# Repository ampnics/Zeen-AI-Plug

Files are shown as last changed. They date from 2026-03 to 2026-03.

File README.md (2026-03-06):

# Zeen-AI-Plug (Zero Green AI Plug)

Top-img

> An open-source, single-channel AI-powered smart plug built on ESP32-S3 with online (Sinric Pro / Google Home / Alexa) and offline timer-based control-designed and shared for the engineering community.

Mode-img

Bottom-img

---

## 📺 Full Course-Hardware Design With AI Co-Pilot

This project is part of a complete open-source hardware design course on YouTube:

**▶️ [Hardware Design With AI Co-Pilot-Full Playlist](https://youtube.com/playlist?list=PLxgq6Jtu7shR8w3cHLHZtZtIrhJVOUqG1&si=Gfo0e48VRceQaZlR)**

The course covers the complete design journey-from schematic to PCB layout, firmware, and cloud integration.

---

---

## 📋 Table of Contents

- [Overview](#-overview)
- [Features](#-features)
- [Hardware Specifications](#-hardware-specifications)
- [System Architecture](#-system-architecture)
- [Operating Modes](#-operating-modes)
- [Repository Structure](#-repository-structure)
- [Getting Started](#-getting-started)
- [Firmware Setup](#-firmware-setup)
- [Cloud & Voice Assistant Integration](#-cloud--voice-assistant-integration)
- [Manufacturing](#-manufacturing)
- [Contributing](#-contributing)
- [License](#-license)

---

## 🔍 Overview

The **Zeen-AI-Plug (ZAP-01A)** is an open-source, single-channel smart plug designed for the engineering community. It combines an ESP32-S3 microcontroller with cloud-based AI voice assistants and a robust offline timer mode, making it functional even without an internet connection.

The board runs on **220VAC mains input**, converting it to **5V DC** via an onboard HLK-5M05 power supply module, and further to **3.3V** via an AMS1117-3.3 LDO - powering the ESP32-S3 and all peripherals.

---

## ✨ Features

- ✅ Single-channel relay control (SPDT)
- ✅ Online mode - Sinric Pro, Google Home, Amazon Alexa
- ✅ Offline mode - RTC-based (DS3231M) timer control
- ✅ USB-C (USB 2.0) for firmware flashing
- ✅ ESD protection on USB lines (USBLC6-2P6)
- ✅ Onboard RTC with battery backup (DS3231M + CH291-1220LF)
- ✅ Status LEDs - Network, Error, General indication
- ✅ Buzzer feedback (MLT-8530)
- ✅ 4x tactile switches for local control
- ✅ MOV surge protection (10D561K)
- ✅ Screw terminal output for load connection
- ✅ Fiducial markers for PCB assembly
- ✅ Fully open-source - Hardware + Firmware

---

## 🔧 Hardware Specifications

| Parameter | Details |
|---|---|
| Microcontroller | ESP32-S3-WROOM-1 |
| Input Voltage | 220V AC |
| Operating Voltage | 5V DC / 3.3V DC |
| Power Supply Module | HLK-5M05 (220VAC → 5VDC) |
| LDO Regulator | AMS1117-3.3 |
| Relay | SPDT — 1 Channel |
| RTC | DS3231M (I2C) |
| RTC Battery | CH291-1220LF (Coin Cell) |
| USB Connector | USB-C (USB 2.0) |
| ESD Protection | USBLC6-2P6 |
| Surge Protection | MOV 10D561K |
| Fuse | 500mA / 250V |
| Status LEDs | Red, Blue, Green |
| Buzzer | MLT-8530 |
| Switches | 4x Tactile + 1x Boot + 1x Reset |
| PCB Tool | KiCad 9.0.1 |
| Board Revision | Rev-v0.1.0A |

---

## 🏗️ System Architecture

```
220V AC Input
     │
     ▼
[F1 Fuse 500mA] ──→ [MOV RV1 Surge Protection]
     │
     ▼
[HLK-5M05] ──→ 5V DC
     │
     ├──→ [Relay K1 SPDT] ──→ Load Output (Screw Terminal J2)
     │
     └──→ [AMS1117-3.3] ──→ 3.3V DC
               │
               ├──→ [ESP32-S3-WROOM-1] ←→ WiFi / BLE
               ├──→ [DS3231M RTC] (I2C)
               ├──→ [Status LEDs]
               ├──→ [Buzzer MLT-8530]
               ├──→ [Tactile Switches x4]
               └──→ [USB-C] ──→ Firmware Flash / Serial Debug
```

---

## ⚙️ Operating Modes

### 🌐 Online Mode
- Connects to WiFi and syncs with **Sinric Pro** cloud platform
- Voice control via **Google Home** and **Amazon Alexa**
- Remote control from anywhere via smartphone app
- Real-time status sync across all platforms

### 📴 Offline Mode
- Fully functional without internet connection
- **DS3231M RTC** maintains accurate time even after power loss
- Timer-based scheduling stored locally
- Local switch control always active in both modes

---

## 📁 Repository Structure

```
Zeen-AI-Plug/
├── Docs/
│   ├── 1-Datasheet/           # Component datasheets
│   ├── 2-Images/              # PCB photos, product images
│   ├── 3-Pin-Mapping/         # ESP32-S3 pin mapping reference
│   └── 4-Testing-Note/        # Test procedures and results
├── Firmware/
│   ├── 1-Test-Code/           # Individual peripheral test sketches
│   └── 2-ZAP-01A-Firmware/    # Main production firmware
├── Hardware/
│   ├── 1-External-3D-Models/  # 3D models for KiCad
│   ├── 2-External-Libraries/  # Custom KiCad footprints & symbols
│   ├── 3-Manufacturing-Files/ # Gerbers, BOM, CPL
│   └── 4-ZAP-01A/             # KiCad project files
└── README.md
```

---

## 🚀 Getting Started

### Prerequisites
- [KiCad 9.0.1](https://www.kicad.org/) — for hardware files
- [Arduino IDE](https://www.arduino.cc/en/software) or [VS Code + ESP-IDF](https://docs.espressif.com/projects/esp-idf/en/latest/) — for firmware
- [Sinric Pro Account](https://sinric.pro/) — for cloud integration
- ESP32-S3 board support package installed in Arduino IDE

### Clone the Repository
```bash
git clone https://github.com/ampnics/Zeen-AI-Plug.git
cd Zeen-AI-Plug
```

---

## 💻 Firmware Setup

### 1. Install ESP32-S3 Board Support
In Arduino IDE → Preferences → add this URL:
```
https://raw.githubusercontent.com/espressif/arduino-esp32/gh-pages/package_esp32_index.json
```
Then: **Tools → Board → Boards Manager → search "esp32" → Install**

### 2. Install Required Libraries
```
Sinric Pro
ArduinoJson
WebSockets
NTPClient
RTClib (for DS3231)
```

### 3. Configure Credentials
Open `Firmware/2-ZAP-01A-Firmware/` and update:
```cpp
For WiFi press "SET" button for 10Sec for updating WiFi Credential via AP Mode
#define APP_KEY         "your_sinric_app_key"
#define APP_SECRET      "your_sinric_app_secret"
#define SWITCH_ID       "your_sinric_device_id"
```

### 4. Flash the Firmware
- Connect via **USB-C**
- Select Board: `ESP32S3 Dev Module`
- Press & hold **BOOT (SW1)** → tap **RESET (SW2)** → release BOOT
- Click **Upload**

---

## ☁️ Cloud & Voice Assistant Integration

### Sinric Pro Setup
1. Create account at [sinric.pro](https://sinric.pro)
2. Add new device → **Smart Plug**
3. Copy **App Key**, **App Secret**, **Device ID** into firmware
4. Flash firmware — device appears online automatically

### Google Home
1. Open Google Home app → **"+" → Set up device**
2. Search **"Sinric Pro"** → Link account
3. Your ZAP-01A plug appears as a controllable device
4. Say: *"Hey Google, turn on the plug"*

### Amazon Alexa
1. Open Alexa app → **Skills & Games**
2. Search **"Sinric Pro"** → Enable skill → Link account
3. Discover devices
4. Say: *"Alexa, turn on the plug"*

---

## 🏭 Manufacturing

Fabrication files are located in `Hardware/3-Manufacturing-Files/` and include:

- **Gerber files** - for PCB fabrication
- **BOM (Bill of Materials)** - component list with values and part numbers
- **CPL (Component Placement List)** - for SMT assembly

> ⚠️ **Safety Warning:** This board operates at **220V AC mains voltage**. Always ensure proper insulation and safety precautions during assembly and testing. Do not touch the board while connected to mains power.

---

## 🤝 Contributing

Contributions are welcome from the engineering community!

1. Fork the repository
2. Create your feature branch: `git checkout -b feature/your-feature`
3. Commit your changes: `git commit -m "feat: add your feature"`
4. Push to the branch: `git push origin feature/your-feature`
5. Open a **Pull Request**

**Commit message convention:**

| Prefix | Use for |
|---|---|
| `hw:` | Hardware / KiCad changes |
| `fw:` | Firmware changes |
| `docs:` | Documentation updates |
| `mfg:` | Manufacturing file updates |
| `fix:` | Bug fixes |

---

## 📄 License

This project is licensed under the **MIT License** — see the [LICENSE](LICENSE) file for details.

You are free to use, modify, and distribute this project for personal and commercial purposes with attribution.

---

## Designed By

**Md Ammar Maniyar** - [LinkedIn](https://www.linkedin.com/in/ammarece/)

## Sponsered By
**NextPCB** - [NextPCB](https://www.nextpcb.com/?code=Ampnics)

## Explore More
**Ampnics** - [Ampnics](https://www.ampnics.com)

*Engineered in India 🇮🇳*

---

## Support the Project

If this project helped you, consider:

- **Starring** this repository
- **Subscribing** to the [YouTube Channel](https://www.youtube.com/@ampnics)
- **Forking** and contributing back to the project

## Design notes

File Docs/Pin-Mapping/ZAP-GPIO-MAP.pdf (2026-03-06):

Zeen-AI-Plug | GPIO Mapping
Device | GPIO | PIN | Type | Comment
3.3V | -- | 2 | PWR
GND | -- | 1/40 | PWR
VBUS | -- | -- | PWR
USB_D+ | IO20 | 14 | PROGRAM/DEBUG
USB_D- | IO19 | 13 | PROGRAM/DEBUG
SW1 | EN | 3 | IN
SW2 | IO0 | 27 | IN
SW3 | IO11 | 19 | IN
SW4 | IO12 | 20 | IN
SW5 | IO13 | 21 | IN
SW6 | IO14 | 22 | IN
RTC_sda | IO8 | 12 | COMM
RTC_scl | IO9 | 17 | COMM
DIS_sda | IO8 | 12 | COMM/OP
DIS_scl | IO9 | 17 | COMM/OP
OPT_dis_sda | IO17 | 10 | COMM/OP
OPT_dis_scl | IO18 | 11 | CPMM/OP
Relay | IO2 | 38 | OP
Network-LED | IO4 | 4 | OP
Status-LED | IO3 | 15 | OP
Buzzer | IO1 | 39 | OP

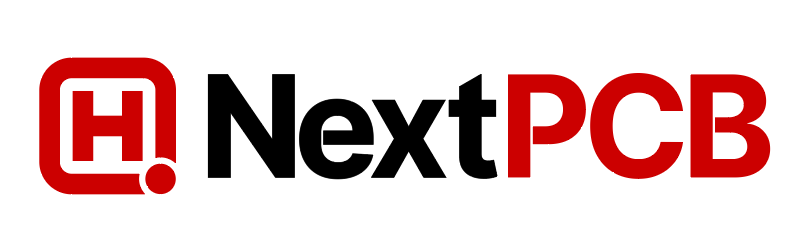
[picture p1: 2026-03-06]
Docs/Images/1746603675-2518-QAgOoc.png

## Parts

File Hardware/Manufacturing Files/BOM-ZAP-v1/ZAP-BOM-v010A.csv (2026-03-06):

S/N | Designator* | Quantity* | Manufacturer Part Number* | Package/Footprint | Description
1 | BT1 | 1 | XDCR-1220-006 | CH291-1220LF:BAT_CH291-1220LF | CH291-1220LF
2 | C1,C12,C13,C16 | 4 | CL21A106KAYNNNE | Capacitor_SMD:C_0805_2012Metric | 10uF
3 | C2,C3,C4,C5,C6,C7,C15,C17 | 8 | TCC0603X7R104K101CT | Capacitor_SMD:C_0603_1608Metric | 100nF
4 | C8,C11,C14 | 3 | TCC0603X7R104K101CT | Capacitor_SMD:C_0603_1608Metric | 100nF/50V
5 | C9 | 1 | MP2104K27C3X6LC | Capacitor_THT:C_Rect_L13.0mm_W6.0mm_P10.00mm_FKS3_FKP3_MKS4 | 0.1uF
6 | C10 | 1 | RVT220UF25V67RV0093 | Capacitor_SMD:CP_Elec_8x10 | 220uF
7 | D1 | 1 | XL-302SURD | LED_THT:LED_D3.0mm | RED
8 | D2 | 1 | B5819W | Diode_SMD:D_SOD-123 | B5819W
9 | D3,D4 | 2 | 1N4148W | Diode_SMD:D_SOD-123 | 1N4148W
10 | D5 | 1 | XL-302UGD | LED_THT:LED_D3.0mm | GREEN
11 | D6 | 1 | XL-302UBD | LED_THT:LED_D3.0mm | BLUE
12 | D7 | 1 | D-060306B1/SS2/B1 | LED_SMD:LED_0603_1608Metric | RED
13 | F1 | 1 | 2009T500mA250V | Fuse:Fuse_Littelfuse_395Series | 500mA 250V
14 | J1 | 1 | HS96L03W2C03 | 0.96 128x64 SSD1315 I2C LCD, OLED, Graphic ROHS | Display
15 | J2 | 1 | DB128V-5.08-4P-GN-S | TerminalBlock:TerminalBlock_bornier-4_P5.08mm | Screw_Terminal_01x04
16 | J3 | 1 | KH-TYPE-C-16P | Connector_USB:USB_C_Receptacle_HCTL_HC-TYPE-C-16P-01A | USB_C_Receptacle_USB2.0_16P
17 | K1 | 1 | SRD-05VDC-SL-C | Relay_THT:Relay_SPDT_Hongfa_HF3F-L-xx-1ZL1T | Relay_SPDT
18 | LS1 | 1 | MLT-8530 | ul_MLT-8530:MLT-8530_JHE | MLT-8530
19 | PS1 | 1 | HLK-5M05 | Converter_ACDC:Converter_ACDC_Hi-Link_HLK-5Mxx | HLK-5M05
20 | Q1,Q2 | 2 | AO3400A | Package_TO_SOT_SMD:SOT-23 | AO3400A
21 | R1,R2,R3,R4 | 4 | RC0603JR-070RL | Resistor_SMD:R_0603_1608Metric | 0R
22 | R5,R14,R15,R16,R17 | 5 | RC0603FR-0710KL | Resistor_SMD:R_0603_1608Metric | 10K
23 | R6,R7,R9,R10,R11 | 5 | RC0603FR-074K7L | Resistor_SMD:R_0603_1608Metric | 4K7
24 | R8 | 1 | MF1/4W-1M±1%-OT52 | Resistor_THT:R_Axial_DIN0204_L3.6mm_D1.6mm_P7.62mm_Horizontal | 1M
25 | R12,R13 | 2 | RC0603FR-075K1L | Resistor_SMD:R_0603_1608Metric | 5K1
26 | R18,R19 | 2 | RC0603JR-070RL | Resistor_SMD:R_0603_1608Metric | 0E
27 | R20 | 1 | RC0603FR-07470RL | Resistor_SMD:R_0603_1608Metric | 470R
28 | R21,R22,R23,R24,R25,R26 | 6 | RC0603FR-071KL | Resistor_SMD:R_0603_1608Metric | 1K
29 | RV1 | 1 | 10D561K | Varistor:RV_Disc_D12mm_W5.8mm_P7.5mm | 10D561K
30 | SW1,SW3,SW4,SW5,SW6 | 5 | TC-1102-C-I-B | Button_Switch_THT:SW_PUSH_6mm | SW_Push
31 | SW2 | 1 | SKRKAHE020 | Button_Switch_SMD:SW_Push_SPST_NO_Alps_SKRK | SW_Push
32 | U1 | 1 | ESP32-S3-WROOM-1-N8 | RF_Module:ESP32-S3-WROOM-1 | ESP32-S3-WROOM-1
33 | U2 | 1 | DS3231SN# | Package_SO:SOIC-16W_7.5x10.3mm_P1.27mm | DS3231M
34 | U3 | 1 | AMS1117-3.3 | Package_TO_SOT_SMD:SOT-223-3_TabPin2 | AMS1117-3.3
35 | U4 | 1 | USBLC6-2P6 | Package_TO_SOT_SMD:SOT-666 | USBLC6-2P6

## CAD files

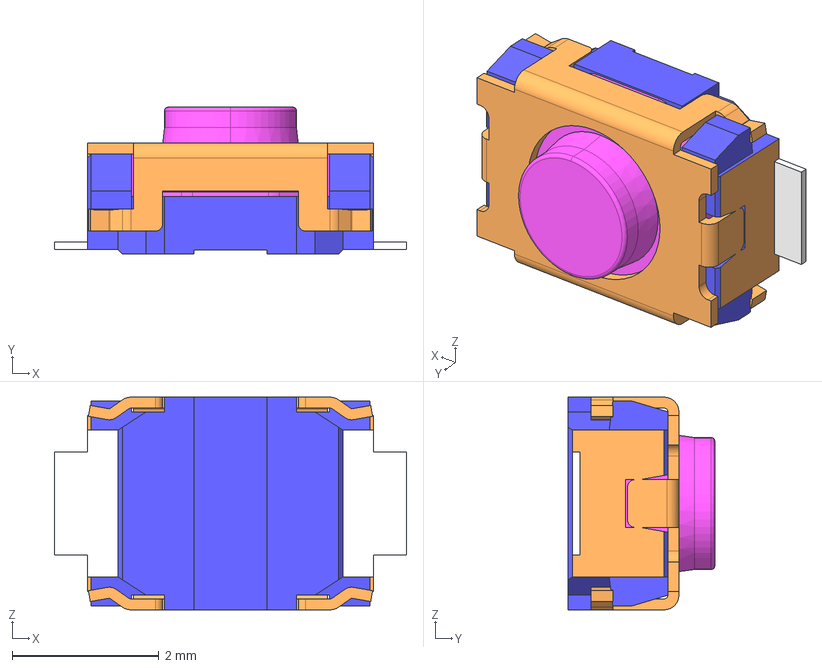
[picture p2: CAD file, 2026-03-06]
Hardware/External-3D-Models/skrkaee010.stp
4.80 x 2.00 x 2.90 mm

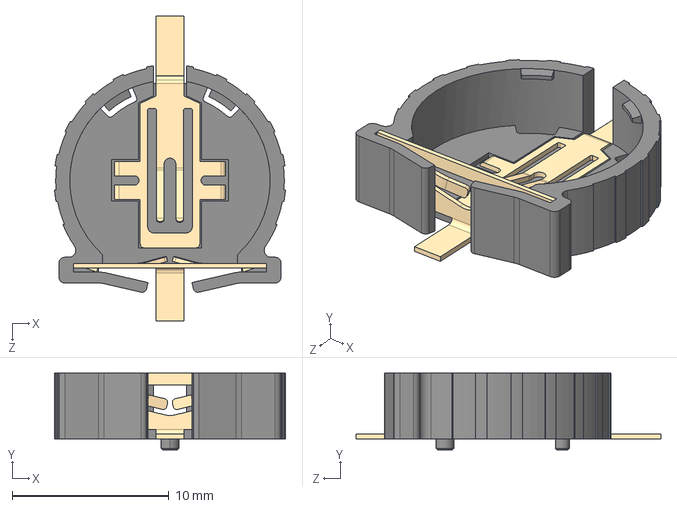
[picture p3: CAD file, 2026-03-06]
Hardware/External-libraries/CH291-1220LF/CH291-1220LF.step
14.7 x 4.90 x 19.4 mm

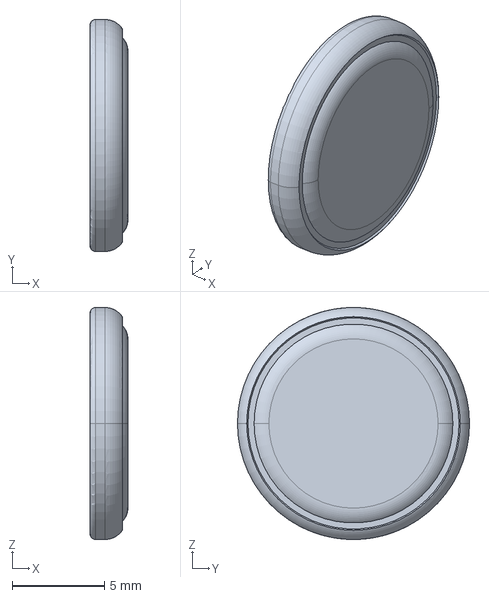
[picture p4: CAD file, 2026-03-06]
Hardware/External-3D-Models/k_cr1220_lithium-cell.stp
2.05 x 12.6 x 12.5 mm

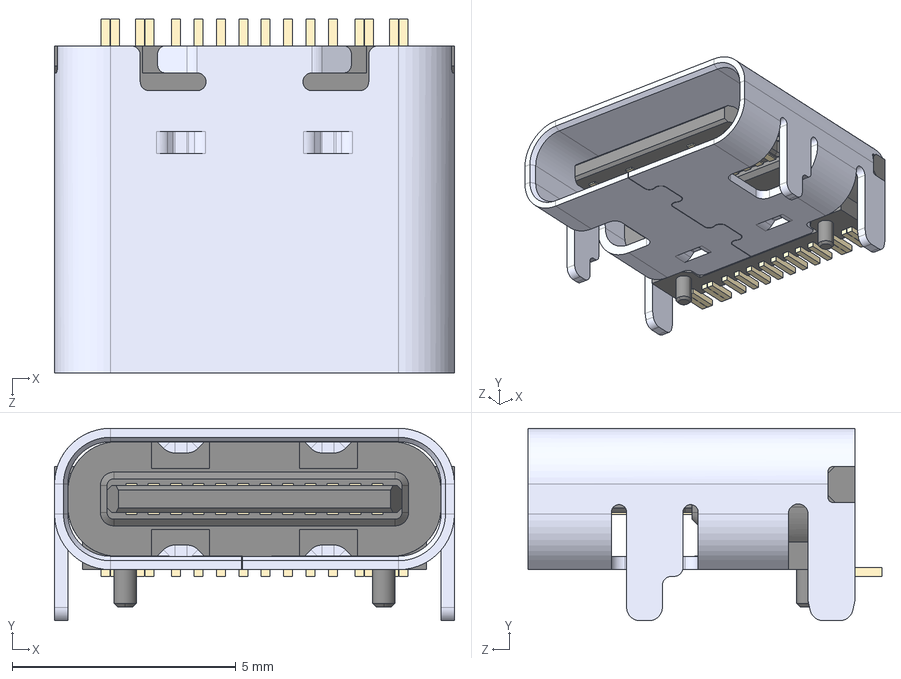
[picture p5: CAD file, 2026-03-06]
Hardware/External-3D-Models/TYPE-C-31-M-12--3DModel-STEP-56544.STEP
8.94 x 4.30 x 7.90 mm

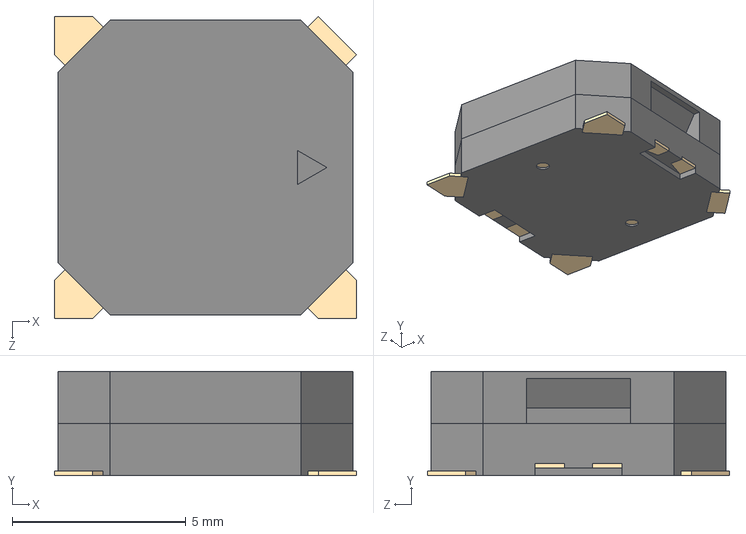
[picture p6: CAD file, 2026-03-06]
Hardware/External-3D-Models/MLT-8530--3DModel-STEP-269445.STEP
8.70 x 3.00 x 8.70 mm

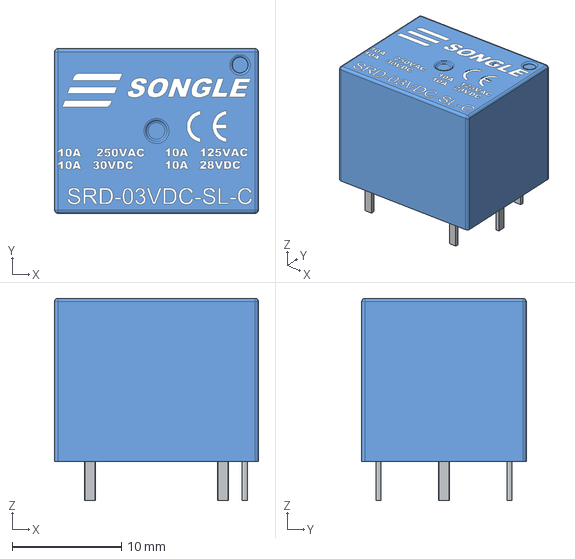
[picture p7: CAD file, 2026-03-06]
Hardware/External-3D-Models/Relay - SRD-03VDC-SL-C.stp
18.7 x 15.1 x 18.6 mm

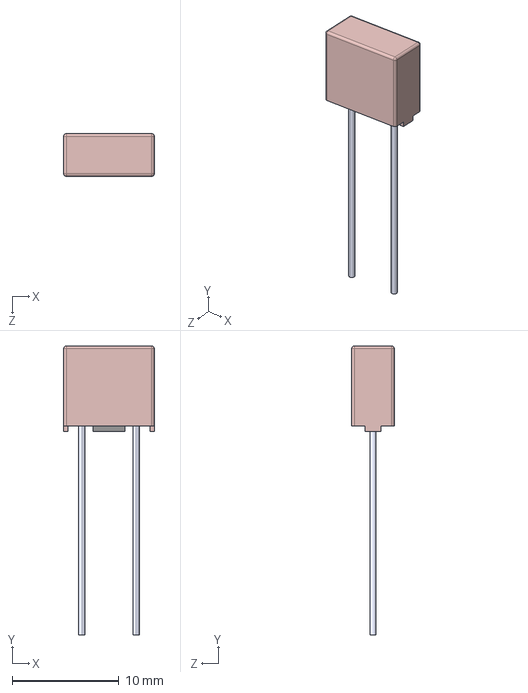
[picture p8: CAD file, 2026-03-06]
Hardware/External-3D-Models/39208000000.STEP
8.50 x 27.1 x 4.00 mm

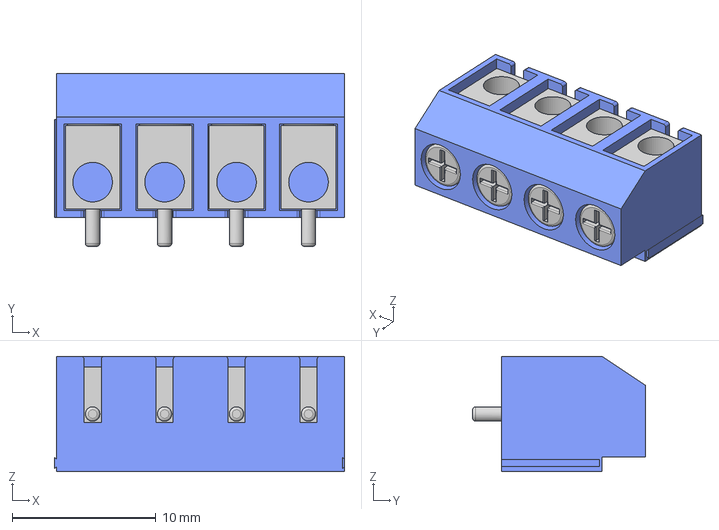
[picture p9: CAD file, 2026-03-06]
Hardware/External-3D-Models/Screw Terminal Block 5mm Blue 4-way.step
20.1 x 12.0 x 8.00 mm

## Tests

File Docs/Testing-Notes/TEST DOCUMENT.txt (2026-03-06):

TEST DOCUMENT 

Zeen-AI-Plug, v0.1.0A|Nov 2025

Test Points
TP1: MCU RESET/EN 
TP2: MCU BOOT
TP3: 5VDC
TP4: GND
TP5: TXD0
TP6: RXD0
TP7: 3.3VDC

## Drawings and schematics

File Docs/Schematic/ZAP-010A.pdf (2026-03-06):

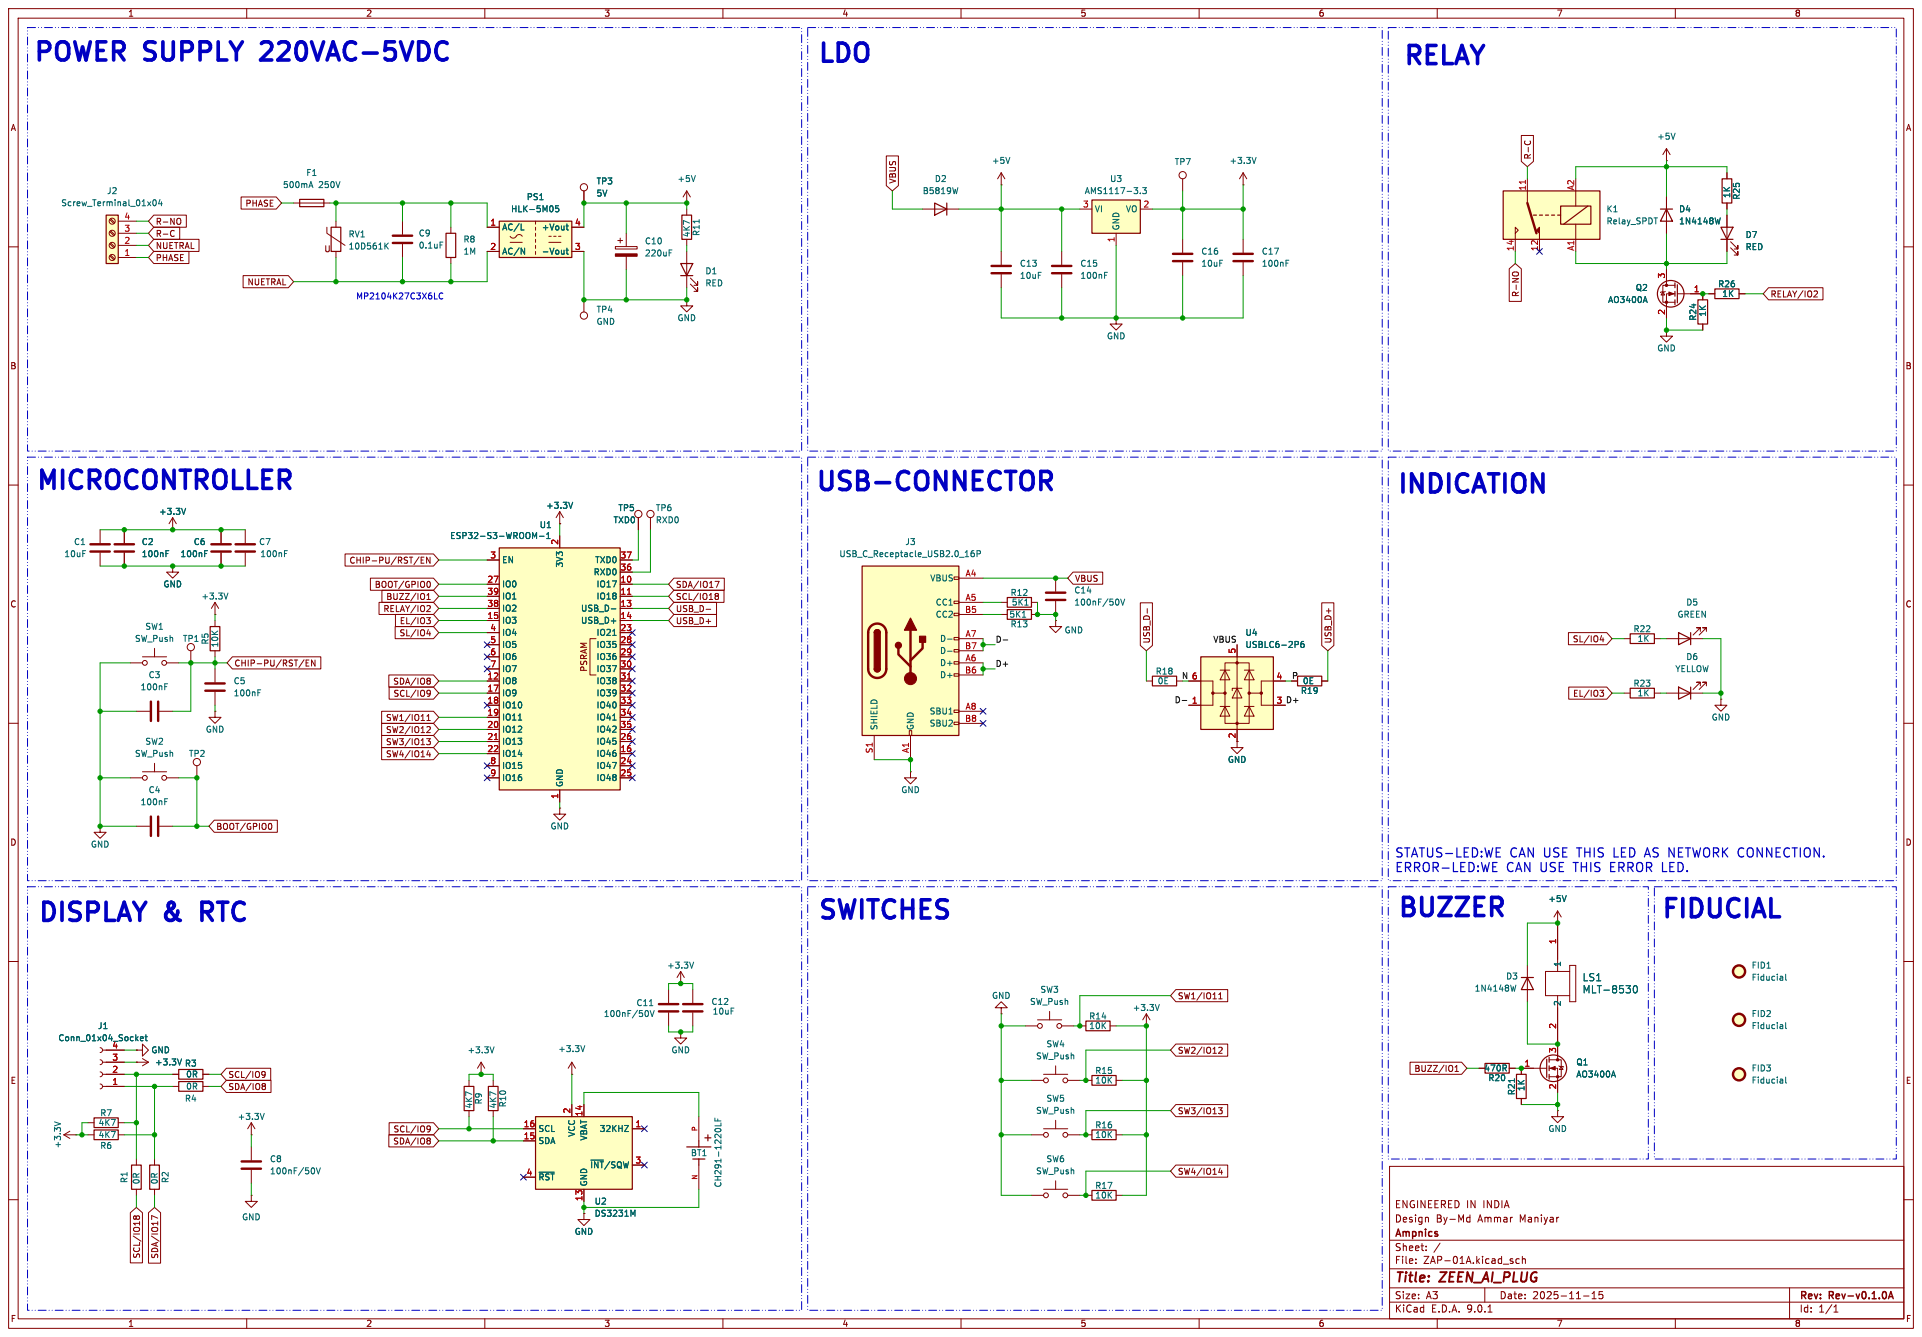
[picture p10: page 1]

P N BT1 CH291-1220LF SCL/IO18 USB_D+ SDA/IO17 NUETRAL R-NO

STATUS-LED:WE CAN USE THIS LED AS NETWORK CONNECTION.
ERROR-LED:WE CAN USE THIS ERROR LED.

File: ZAP-01A.kicad_sch Sheet: / Ampnics

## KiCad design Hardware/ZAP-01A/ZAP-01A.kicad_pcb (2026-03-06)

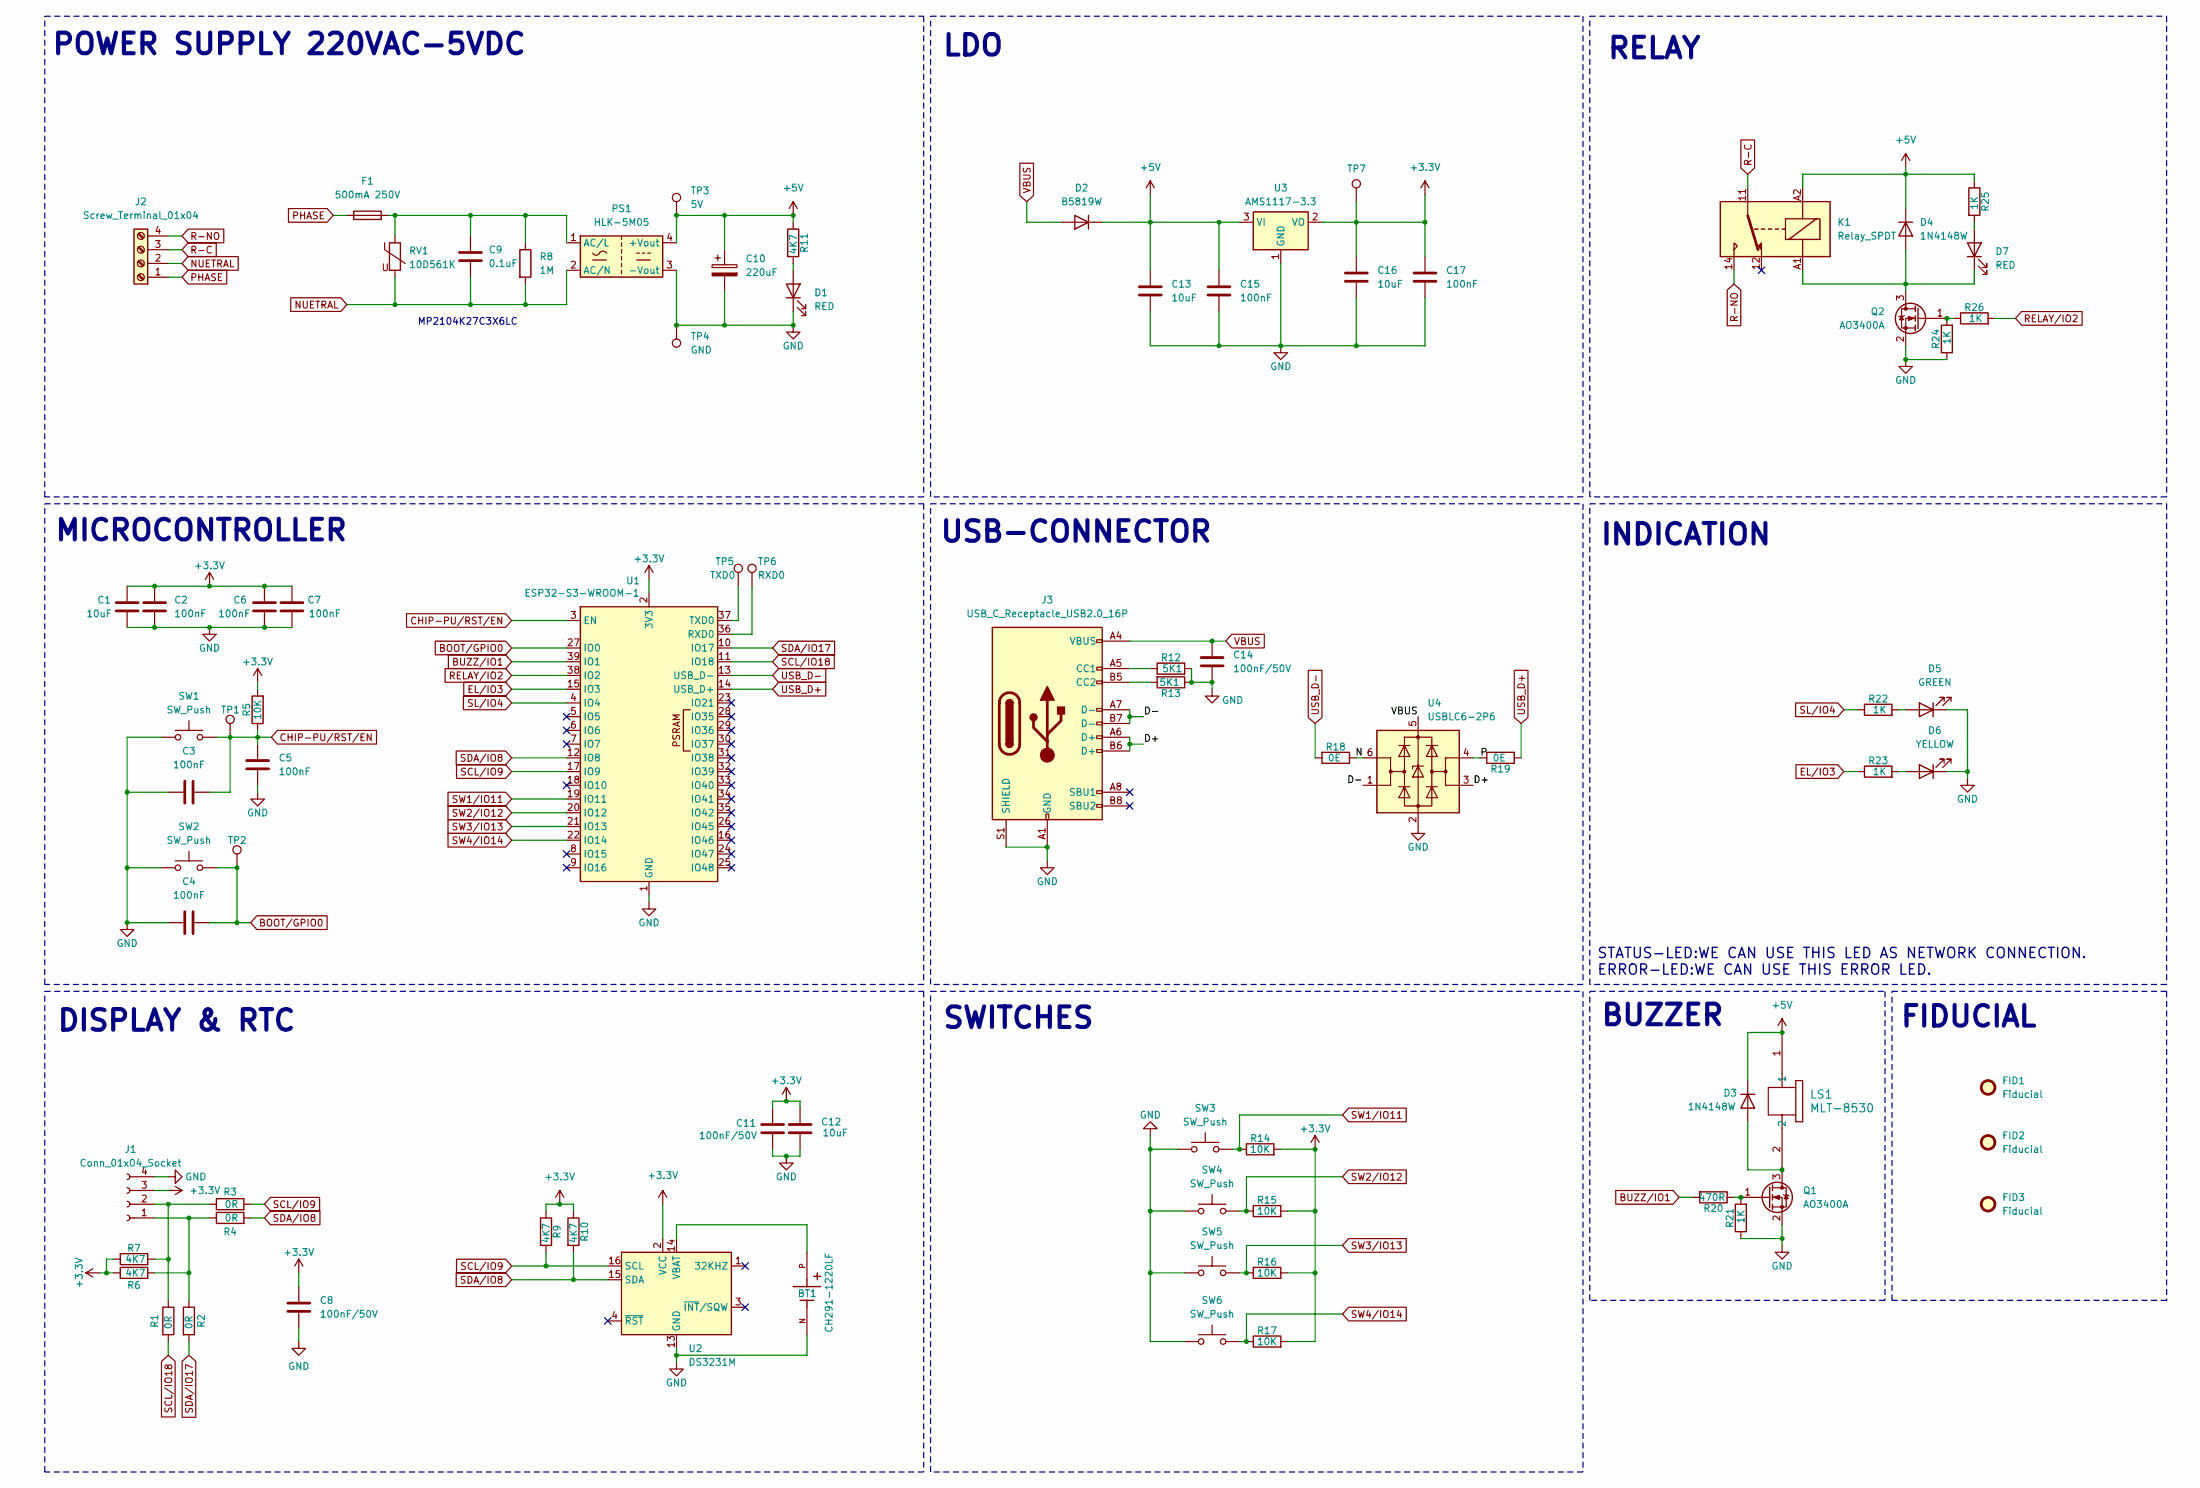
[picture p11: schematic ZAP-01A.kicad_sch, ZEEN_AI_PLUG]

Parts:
BT1: CH291-1220LF; BAT_CH291-1220LF; PARTREV A
C1, C12, C13, C16: 10uF; C_0805_2012Metric
C2, C3, C4, C5, C6, C7, C15, C17: 100nF; C_0603_1608Metric
C8, C11, C14: 100nF/50V; C_0603_1608Metric
C9: 0.1uF; C_Rect_L13.0mm_W6.0mm_P10.00mm_FKS3_FKP3_MKS4
C10: 220uF; CP_Elec_8x10
D1: RED; LED_D3.0mm
D2: B5819W; D_SOD-123
D3, D4: 1N4148W; D_SOD-123
D5: GREEN; LED_D3.0mm
D6: YELLOW; LED_D3.0mm
D7: RED; LED_0603_1608Metric
F1: 500mA 250V; Fuse_Littelfuse_395Series
FID1, FID2, FID3: Fiducial; Fiducial_0.75mm_Mask1.5mm
J1: Conn_01x04_Socket; PinSocket_1x04_P2.54mm_Vertical
J2: Screw_Terminal_01x04; TerminalBlock_bornier-4_P5.08mm
J3: USB_C_Receptacle_USB2.0_16P; USB_C_Receptacle_HCTL_HC-TYPE-C-16P-01A
K1: Relay_SPDT; Relay_SPDT_Hongfa_HF3F-L-xx-1ZL1T
LS1: MLT-8530; MLT-8530_JHE
PS1: HLK-5M05; Converter_ACDC_Hi-Link_HLK-5Mxx
Q1, Q2: AO3400A; SOT-23
R1, R2, R3, R4: 0R; R_0603_1608Metric
R5, R14, R15, R16, R17: 10K; R_0603_1608Metric
R6, R7, R9, R10, R11: 4K7; R_0603_1608Metric
R8: 1M; R_Axial_DIN0204_L3.6mm_D1.6mm_P7.62mm_Horizontal
R12, R13: 5K1; R_0603_1608Metric
R18, R19: 0E; R_0603_1608Metric
R20: 470R; R_0603_1608Metric
R21, R22, R23, R24, R25, R26: 1K; R_0603_1608Metric
RV1: 10D561K; RV_Disc_D12mm_W5.8mm_P7.5mm
SW1, SW3, SW4, SW5, SW6: SW_Push; SW_PUSH_6mm
SW2: SW_Push; SW_Push_SPST_NO_Alps_SKRK
TP1, TP2, TP7: 3.3V; TestPoint_Pad_D1.5mm
TP3: 5V; TestPoint_Pad_D1.5mm
TP4: GND; TestPoint_Pad_D1.5mm
TP5: TXD0; TestPoint_Pad_D1.5mm
TP6: RXD0; TestPoint_Pad_D1.5mm
U1: ESP32-S3-WROOM-1
U2: DS3231M; SOIC-16W_7.5x10.3mm_P1.27mm
U3: AMS1117-3.3; SOT-223-3_TabPin2
U4: USBLC6-2P6; SOT-666

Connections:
+3.3V: C1.1, C2.1, C6.1, C7.1, C8.1, C11.1, C12.1, C16.1, C17.1, J1.3, R5.2, R6.1, R7.1, R9.1, R10.1, R14.2, R15.2, R16.2, R17.2, TP7.1, U1.2 (3V3), U2.2 (VCC), U3.2 (VO)
+5V: C10.1, C13.1, C15.1, D2.1 (K), D3.1 (K), D4.1 (K), K1.A2, LS1.1, PS1.4 (+Vout), R11.1, R25.1, TP3.1, U3.3 (VI)
/D+: J3.A6 (D+), J3.B6 (D+), U4.3 (I/O2)
/D-: J3.A7 (D-), J3.B7 (D-), U4.1 (I/O1)
/N: R18.1, U4.6 (I/O1)
/P: R19.2, U4.4 (I/O2)
BOOT/GPIO0: C4.2, SW2.2, TP2.1, U1.27 (IO0)
BUZZ/IO1: R20.2, U1.39 (IO1)
CHIP-PU/RST/EN: C3.2, C5.1, R5.1, SW1.2, TP1.1, U1.3 (EN)
EL/IO3: R23.1, U1.15 (IO3)
GND: BT1.N, C1.2, C2.2, C3.1, C4.1, C5.2, C6.2, C7.2, C8.2, C10.2, C11.2, C12.2, C13.2, C14.2, C15.2, C16.2, C17.2, D1.1 (K), D5.1 (K), D6.1 (K), J1.4, J3.A1 (GND), J3.A12 (GND), J3.B1 (GND), J3.B12 (GND), J3.S1 (SHIELD), PS1.3 (-Vout), Q1.2 (S), Q2.2 (S), R12.2, R13.1, R21.1, R24.1, SW1.1, SW2.1, SW3.1, SW4.1, SW5.1, SW6.1, TP4.1, U1.1 (GND), U1.40 (GND), U1.41 (GND), U2.5 (GND), U2.6 (GND), U2.7 (GND), U2.8 (GND), U2.9 (GND), U2.10 (GND), U2.11 (GND), U2.12 (GND), U2.13 (GND), U3.1 (GND), U4.2 (GND)
unnamed: D1.2 (A), R11.2
unnamed: D3.2 (A), LS1.2, Q1.3 (D)
unnamed: D4.2 (A), D7.1 (K), K1.A1, Q2.3 (D)
unnamed: D5.2 (A), R22.2
unnamed: D6.2 (A), R23.2
unnamed: D7.2 (A), R25.2
unnamed: J1.1, R2.1, R4.1, R6.2
unnamed: J1.2, R1.1, R3.1, R7.2
unnamed: J3.A5 (CC1), R12.1
unnamed: J3.B5 (CC2), R13.2
unnamed: Q1.1 (G), R20.1, R21.2
unnamed: Q2.1 (G), R24.2, R26.1
unnamed: TP6.1, U1.36 (RXD0)
unnamed: TP5.1, U1.37 (TXD0)
unnamed: BT1.P, U2.14 (VBAT)
PHASE: F1.1, J2.1
R-C: J2.3, K1.11
R-NO: J2.4, K1.14
RELAY/IO2: R26.2, U1.38 (IO2)
SCL/IO9: R3.2, R9.2, U1.17 (IO9), U2.16 (SCL)
SCL/IO18: R1.2, U1.11 (IO18)
SDA/IO8: R4.2, R10.2, U1.12 (IO8), U2.15 (SDA)
SDA/IO17: R2.2, U1.10 (IO17)
SL/IO4: R22.1, U1.4 (IO4)
SW1/IO11: R14.1, SW3.2, U1.19 (IO11)
SW2/IO12: R15.1, SW4.2, U1.20 (IO12)
SW3/IO13: R16.1, SW5.2, U1.21 (IO13)
SW4/IO14: R17.1, SW6.2, U1.22 (IO14)
USB_D+: R19.1, U1.14 (USB_D+)
USB_D-: R18.2, U1.13 (USB_D-)
VBUS: C14.1, D2.2 (A), J3.A4 (VBUS), J3.A9 (VBUS), J3.B4 (VBUS), J3.B9 (VBUS), U4.5 (VBUS)

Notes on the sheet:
MICROCONTROLLER
BUZZER
DISPLAY & RTC
SWITCHES
INDICATION
MP2104K27C3X6LC
USB-CONNECTOR
RELAY
FIDUCIAL
LDO
POWER SUPPLY 220VAC-5VDC
STATUS-LED:WE CAN USE THIS LED AS NETWORK CONNECTION. ERROR-LED:WE CAN USE THIS ERROR LED.

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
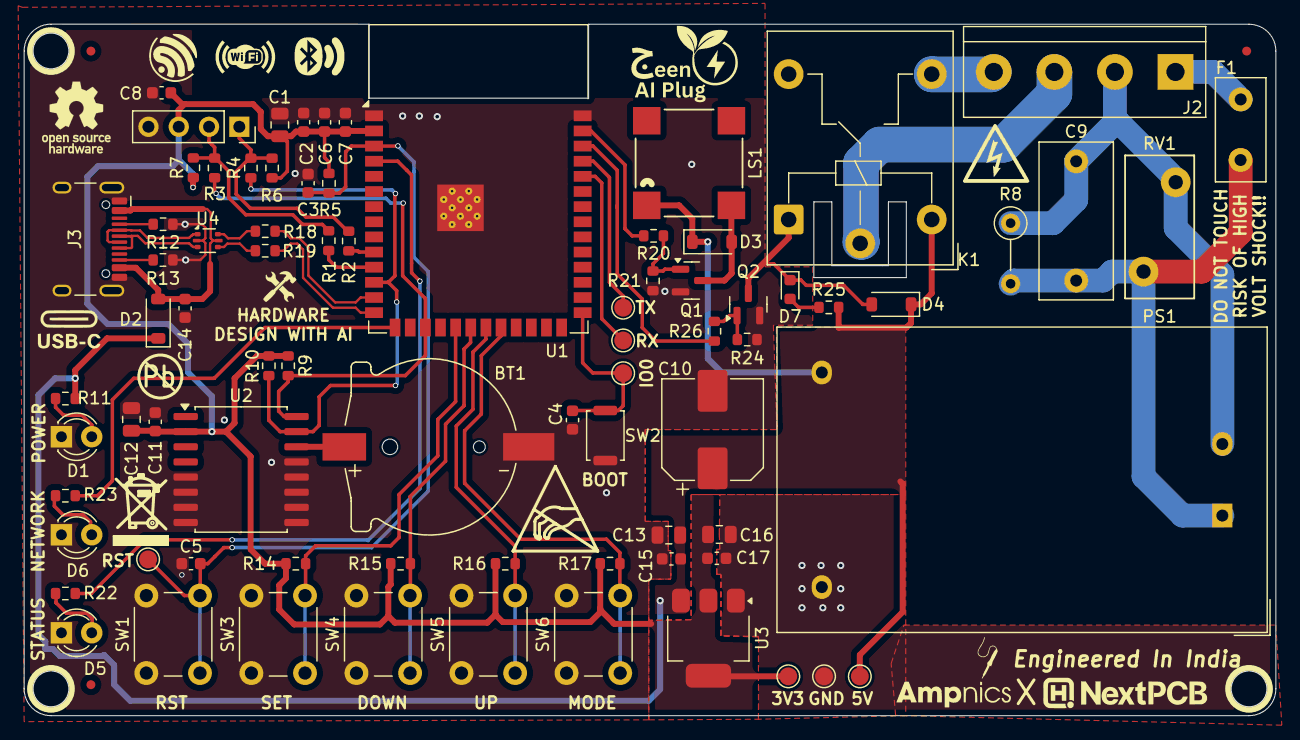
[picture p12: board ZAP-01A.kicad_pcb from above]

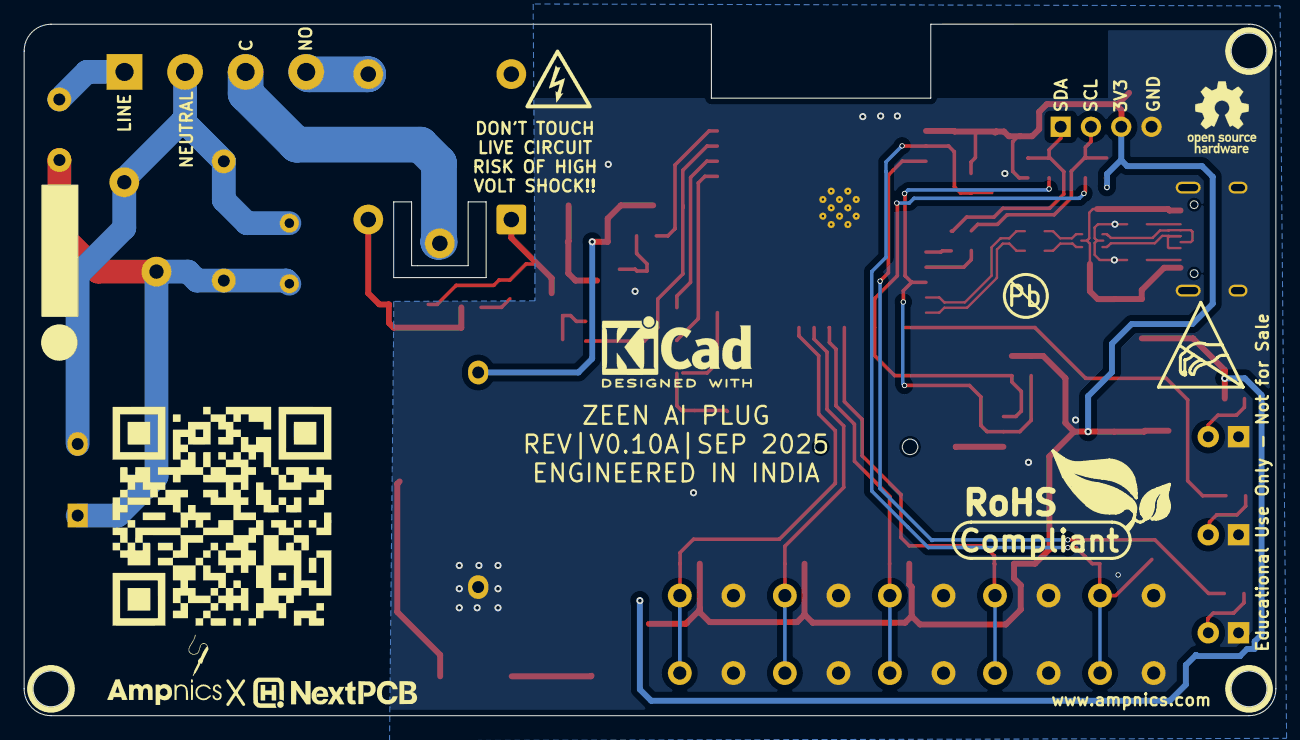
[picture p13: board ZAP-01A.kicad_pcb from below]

Board: 2 copper layers, 105.0 x 58.0 mm, 87 parts (3 on the bottom side), 44 nets.

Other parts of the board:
Sign-Antistatic: Val**; LOGO_ANTISTATIC_1
Sign-Antistatic#2: Val**; LOGO_ANTISTATIC_1
Sign-PbFree: LOGO_PBFREE
Sign-PbFree#2: LOGO_PBFREE
Sign-RecycleBin: LOGO_RECYCLEBIN_1
Sign-RoHS: Val**; LOGO_ROHS_1

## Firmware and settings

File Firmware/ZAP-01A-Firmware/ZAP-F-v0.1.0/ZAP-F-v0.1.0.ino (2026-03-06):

/* Zeen AI Plug - ESP32-S3 Timer Board (Online + Offline)
   Features:
   - Splash + C-scale on startup
   - Mode select: ONLINE / OFFLINE
   - ONLINE: WiFiManager + SinricPro control + OLED feedback
   - OFFLINE: Timer countdown with relay, buzzer & OLED
   - Perfect button debounce, single press & long press
   - Relay status LED
*/

#include <Arduino.h>
#include <WiFi.h>
#include <WiFiManager.h>
#include "SinricPro.h"
#include "SinricProSwitch.h"
#include <Wire.h>
#include <Adafruit_GFX.h>
#include <Adafruit_SSD1306.h>

// ---------- PIN DEFINITIONS ----------
#define PIN_SET       11
#define PIN_DOWN      12
#define PIN_UP        13
#define PIN_MODE      14
#define BUZZER_PIN    1
#define RELAY_PIN     2
#define PIN_RELAY_LED 4
#define WIFI_LED      3

// ---------- OLED ----------
#define SCREEN_WIDTH 128
#define SCREEN_HEIGHT 64
#define OLED_RESET -1
#define OLED_ADDR 0x3C
Adafruit_SSD1306 display(SCREEN_WIDTH, SCREEN_HEIGHT, &Wire, OLED_RESET);
bool oledReady = false;

// ---------- TIMING ----------
#define BOOT_MESSAGE_MS     3000
#define DISPLAY_REFRESH_MS  150
#define BUTTON_DEBOUNCE     60
#define HOLD_REPEAT_DELAY   500
#define HOLD_REPEAT_RATE    110

// ---------- STATE MACHINE ----------
enum SystemState {STATE_BOOT, STATE_MODE_SELECT, STATE_SET_TIME, STATE_COUNTDOWN, STATE_ONLINE};
SystemState currentState;

// ---------- TIME VARIABLES ----------
uint8_t cursor = 0;
uint32_t setH = 0, setM = 0, setS = 0;
uint32_t remainingSeconds = 0;
unsigned long lastCountdownTick = 0;
bool countdownRunning = false;

// ---------- BUTTON STRUCT ----------
struct Btn { int pin; bool stable = HIGH; bool last = HIGH; unsigned long lastChange = 0; unsigned long pressedAt = 0; unsigned long lastRepeat = 0; bool handled = false; };
Btn bSet = {PIN_SET}, bUp = {PIN_UP}, bDown = {PIN_DOWN}, bMode = {PIN_MODE};

// ---------- WiFi + SinricPro ----------
WiFiManager wm;
volatile bool systemRunning = false;
unsigned long lastAnimMillis = 0;
#define APP_KEY     "e9130a32-30ea-4935-84b1-90f55e0df98e"
#define APP_SECRET  "146329c0-e815-4bd2-a43a-5ed70126cb2b-4f93b63c-ca2e-46a0-8f7e-2d3c5975c8cc"
#define SWITCH_ID_1 "67c80f958d6ea96ddf98682d"

// ---------- BUZZER ----------
void beep(uint16_t f = 3000, uint16_t d = 30) { tone(BUZZER_PIN, f, d); }

void playStartupTone() { const uint32_t notes[]={262,294,330,349,392,440,494,523}; for(int i=0;i<8;i++){beep(notes[i],200);delay(50);} delay(500); }

// ---------- BUTTON PROCESSING ----------
void readBtn(Btn &b) {
  bool r = digitalRead(b.pin);
  if(r!=b.last){b.lastChange=millis();b.last=r;}
  if(millis()-b.lastChange>BUTTON_DEBOUNCE){
    if(r!=b.stable){
      b.stable=r;
      if(b.stable==LOW){b.pressedAt=millis();b.lastRepeat=millis();b.handled=false;}
      else b.handled=false;
    }
  }
}
bool singlePress(Btn &b){if(b.stable==LOW&&!b.handled&&millis()-b.pressedAt<HOLD_REPEAT_DELAY){b.handled=true;beep();return true;}return false;}
bool repeatPress(Btn &b){if(b.stable==LOW&&millis()-b.pressedAt>=HOLD_REPEAT_DELAY&&millis()-b.lastRepeat>=HOLD_REPEAT_RATE){b.lastRepeat=millis();beep();return true;}return false;}

// ---------- DISPLAY HELPERS ----------
void splash(){display.clearDisplay();display.setTextColor(SSD1306_WHITE);display.setTextSize(2);display.setCursor(10,20);display.println("Zeen AI");display.setTextSize(1);display.setCursor(10,45);display.println("Plug");display.display();}
void showMode(){
  display.clearDisplay();display.setTextSize(1);display.setCursor(10,5);display.println("Select Mode");
  display.setTextSize(2);display.setCursor(10,25);if(cursor==0)display.print("> ");else display.print("  ");display.print("ONLINE");
  display.setTextSize(2);display.setCursor(10,45);if(cursor==1)display.print("> ");else display.print("  ");display.print("OFFLINE");display.display();
}
void showSetTime(){
  char buf[16];sprintf(buf,"%02d:%02d:%02d",setH,setM,setS);
  display.clearDisplay();display.setTextSize(1);display.setCursor(10,5);display.println("Set Time");
  display.setTextSize(2);int16_t x1,y1;uint16_t w,h;display.getTextBounds(buf,0,0,&x1,&y1,&w,&h);
  display.setCursor((128-w)/2,25);display.println(buf);
  int cursorX=(128-w)/2;if(cursor==1)cursorX+=30;else if(cursor==2)cursorX+=65;
  display.fillRect(cursorX,47,22,3,SSD1306_WHITE);display.display();
}
void showCountdown(){
  char buf[16];uint32_t sec=remainingSeconds;uint32_t h=sec/3600;sec%=3600;uint32_t m=sec/60;sec%=60;
  sprintf(buf,"%02d:%02d:%02d",h,m,sec);
  display.clearDisplay();display.setTextSize(1);display.setCursor(10,5);display.println("OFFLINE");
  display.setTextSize(2);display.setCursor(10,25);display.println(buf);display.display();
}

// ---------- COUNTDOWN ----------
void startCountdown(){remainingSeconds=setH*3600+setM*60+setS;if(!remainingSeconds)return;countdownRunning=true;lastCountdownTick=millis();digitalWrite(RELAY_PIN,HIGH);digitalWrite(PIN_RELAY_LED,HIGH);}
void stopCountdown(){countdownRunning=false;digitalWrite(RELAY_PIN,LOW);digitalWrite(PIN_RELAY_LED,LOW);}
void updateCountdown(){if(!countdownRunning)return;if(millis()-lastCountdownTick>=1000){lastCountdownTick+=1000;if(remainingSeconds>0)remainingSeconds--;if(!remainingSeconds)stopCountdown();}}

// ---------- STATE CONTROL ----------
void enterState(SystemState s){
  currentState=s;
  if(s==STATE_BOOT){splash();playStartupTone();}
  else if(s==STATE_MODE_SELECT){cursor=0;showMode();}
  else if(s==STATE_SET_TIME){setH=setM=setS=0;cursor=0;showSetTime();}
  else if(s==STATE_COUNTDOWN){startCountdown();showCountdown();}
}

// ---------- ONLINE MODE ----------
bool onPowerState1(const String &deviceId,bool &state){
  systemRunning=state;
  digitalWrite(RELAY_PIN,state?HIGH:LOW);digitalWrite(PIN_RELAY_LED,state?HIGH:LOW);
  if(state){beep(660,80);beep(880,80);}else{beep(220,150);}
  return true;
}

void tryConnectOrPortal(){
  display.clearDisplay();display.setTextSize(1);display.setCursor(0,8);display.println("Connecting WiFi...");display.display();
  WiFi.mode(WIFI_STA);WiFi.begin();
  unsigned long start=millis();while(WiFi.status()!=WL_CONNECTED&&millis()-start<10000)delay(200);
  if(WiFi.status()==WL_CONNECTED){digitalWrite(WIFI_LED,HIGH);display.clearDisplay();display.setCursor(0,8);display.println("WiFi Connected");display.display();delay(900);return;}
  display.clearDisplay();display.setCursor(0,8);display.println("AP Mode");display.display();
  wm.setTimeout(300);wm.startConfigPortal("ZeenAI-Setup");
}

// ---------- SET BUTTON LONG PRESS ----------
void resetWiFiAndRestart(){wm.resetSettings();WiFi.disconnect(true,true);ESP.restart();}
void handleSetButton(){static unsigned long pressStart=0;static bool longPressed=false;int val=digitalRead(PIN_SET);if(val==LOW){if(pressStart==0)pressStart=millis();if(!longPressed&&millis()-pressStart>=5000){longPressed=true;resetWiFiAndRestart();}}else{pressStart=0;longPressed=false;}}

// ---------- SETUP ----------
void setup(){
  Serial.begin(115200);delay(50);
  pinMode(RELAY_PIN,OUTPUT);pinMode(PIN_RELAY_LED,OUTPUT);pinMode(PIN_SET,INPUT_PULLUP);
  pinMode(PIN_UP,INPUT_PULLUP);pinMode(PIN_DOWN,INPUT_PULLUP);pinMode(PIN_MODE,INPUT_PULLUP);pinMode(WIFI_LED,OUTPUT);
  digitalWrite(RELAY_PIN,LOW);digitalWrite(PIN_RELAY_LED,LOW);digitalWrite(WIFI_LED,LOW);
  if(display.begin(SSD1306_SWITCHCAPVCC,OLED_ADDR)){oledReady=true;display.clearDisplay();display.display();}
  enterState(STATE_BOOT);delay(BOOT_MESSAGE_MS);
  enterState(STATE_MODE_SELECT);
}

// ---------- LOOP ----------
void loop(){
  readBtn(bSet);readBtn(bUp);readBtn(bDown);readBtn(bMode);
  static unsigned long lastUI=0;

  // MODE SELECT
  if(currentState==STATE_MODE_SELECT){
    if(singlePress(bUp)||repeatPress(bUp)){cursor=0;showMode();}
    if(singlePress(bDown)||repeatPress(bDown)){cursor=1;showMode();}
    if(singlePress(bSet)){
      if(cursor==0){ // ONLINE
        enterState(STATE_ONLINE);tryConnectOrPortal();
        SinricProSwitch &mySwitch=SinricPro[SWITCH_ID_1];mySwitch.onPowerState(onPowerState1);
        SinricPro.begin(APP_KEY,APP_SECRET);
      }else enterState(STATE_SET_TIME); // OFFLINE
    }
  }

  // SET TIME
  else if(currentState==STATE_SET_TIME){
    if(singlePress(bMode))cursor=(cursor+1)%3;
    if(singlePress(bUp)||repeatPress(bUp)){if(cursor==0&&setH<99)setH++;if(cursor==1&&setM<59)setM++;if(cursor==2&&setS<59)setS++;}
    if(singlePress(bDown)||repeatPress(bDown)){if(cursor==0&&setH>0)setH--;if(cursor==1&&setM>0)setM--;if(cursor==2&&setS>0)setS--;}
    if(singlePress(bSet)){if(setH+setM+setS>0)enterState(STATE_COUNTDOWN);}
    if(millis()-lastUI>DISPLAY_REFRESH_MS){lastUI=millis();showSetTime();}
  }

  // COUNTDOWN
  else if(currentState==STATE_COUNTDOWN){
    updateCountdown();
    if(millis()-lastUI>DISPLAY_REFRESH_MS){lastUI=millis();showCountdown();}
    if(singlePress(bSet)){stopCountdown();enterState(STATE_SET_TIME);}
    if(!countdownRunning&&remainingSeconds==0){display.clearDisplay();display.setTextSize(2);display.setCursor(25,25);display.println("TIME UP");display.display();delay(2000);enterState(STATE_SET_TIME);}
  }

  // ONLINE RUN
  else if(currentState==STATE_ONLINE){
    SinricPro.handle();digitalWrite(WIFI_LED,WiFi.status()==WL_CONNECTED?HIGH:LOW);
    handleSetButton();
    if(systemRunning){if(oledReady&&millis()-lastAnimMillis>450){lastAnimMillis=millis();display.clearDisplay();display.setTextSize(2);display.setCursor(10,0);display.println("SYSTEM ON");display.display();}}
    else{if(oledReady&&millis()-lastAnimMillis>450){lastAnimMillis=millis();display.clearDisplay();display.setTextSize(2);display.setCursor(6,8);display.println("SYSTEM OFF");display.display();}}
  }
}

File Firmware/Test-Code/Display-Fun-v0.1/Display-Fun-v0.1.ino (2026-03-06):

/* Zeen AI Plug - ESP32-S3 Timer Board
   Features:
   - Boot splash "Zeen AI Plug"
   - Mode select: ONLINE / OFFLINE (UP/DOWN + SET)
   - ONLINE: try stored WiFi, allow captive portal provisioning via WiFiManager if needed
       - SET long-press (6s) during online state = WiFi reset + "WiFi Reset" + LED blink 3x (100ms)
   - OFFLINE: Set countdown time (HH:MM:SS) using MODE (cursor), UP/DOWN, SET to start
   - OLED display (Adafruit SSD1306)
   - Button debounce & long press detection
*/

#include <Wire.h>
#include <WiFi.h>
#include <WiFiClient.h>
#include <WiFiManager.h> // WiFiManager by tzapu (ESP32 compatible fork)
#include <Adafruit_GFX.h>
#include <Adafruit_SSD1306.h>

// ---------- CONFIG ----------
#define SCREEN_WIDTH 128
#define SCREEN_HEIGHT 64
#define OLED_RESET -1
#define OLED_ADDR 0x3C

Adafruit_SSD1306 display(SCREEN_WIDTH, SCREEN_HEIGHT, &Wire, OLED_RESET);

// Pins (as per user)
const int PIN_SET = 11;   // IO11
const int PIN_DOWN = 12;  // IO12
const int PIN_UP   = 13;  // IO13
const int PIN_MODE = 14;  // IO14
const int PIN_LED  = 3;   // IO3 status LED

// Timing constants
const unsigned long BOOT_MESSAGE_MS = 3000;
const unsigned long WIFI_CONN_TIMEOUT_MS = 20000; // try connecting for 20s before portal
const unsigned long DISPLAY_REFRESH_MS = 200;
const unsigned long BUTTON_DEBOUNCE_MS = 50;
const unsigned long SET_LONGPRESS_MS = 6000; // 6 seconds

// ---------- STATES ----------
enum SystemState {
  STATE_BOOT,
  STATE_MODE_SELECT,
  STATE_ONLINE_CONNECTING,
  STATE_ONLINE_PORTAL,      // captive portal active
  STATE_ONLINE_CONNECTED,
  STATE_WIFI_RESET_BLINK,
  STATE_OFFLINE_SET_TIME,
  STATE_OFFLINE_COUNTDOWN
};

SystemState currentState = STATE_BOOT;

// ---------- Button helper ----------
struct Button {
  int pin;
  bool lastState;
  bool stableState;
  unsigned long lastDebounce;
  unsigned long pressedMillis; // when pressed started (for long press)
  bool pressedHandled;         // whether long press has been handled
};

Button btnSet   = {PIN_SET, HIGH, HIGH, 0, 0, false};
Button btnUp    = {PIN_UP, HIGH, HIGH, 0, 0, false};
Button btnDown  = {PIN_DOWN, HIGH, HIGH, 0, 0, false};
Button btnMode  = {PIN_MODE, HIGH, HIGH, 0, 0, false};

// readButtons() updates stableState and tracks long press start time for SET
void readButton(Button &b) {
  bool reading = digitalRead(b.pin);
  if (reading != b.lastState) {
    b.lastDebounce = millis();
  }
  if ((millis() - b.lastDebounce) > BUTTON_DEBOUNCE_MS) {
    if (reading != b.stableState) {
      b.stableState = reading;
      // change of stable state: if pressed (active LOW), record press start
      if (b.stableState == LOW) {
        b.pressedMillis = millis();
        b.pressedHandled = false;
      } else {
        b.pressedMillis = 0;
        b.pressedHandled = false;
      }
    }
  }
  b.lastState = reading;
}

// helper queries
bool buttonIsPressed(Button &b) {
  return (b.stableState == LOW);
}
bool buttonWasJustPressed(Button &b) {
  // we detect press via lastDebounce transition; but for simplicity, call after readButton and
  // check if pressedMillis was just set within a short time window.
  // This function is called each loop iteration; to detect edges better, you can add more state.
  // For our simple use, we will detect rising edge by checking pressedMillis > 0 and < 200ms old.
  if (b.pressedMillis != 0 && (millis() - b.pressedMillis) < 200 && !b.pressedHandled) {
    // treat as short press event (the handler should set pressedHandled true)
    return true;
  }
  return false;
}

bool buttonLongPress(Button &b, unsigned long threshold) {
  if (b.pressedMillis != 0 && (millis() - b.pressedMillis >= threshold) && !b.pressedHandled) {
    b.pressedHandled = true;
    return true;
  }
  return false;
}

// ---------- Display helpers ----------
unsigned long lastDisplay = 0;

void showSplash() {
  display.clearDisplay();
  display.setTextSize(2);
  display.setTextColor(SSD1306_WHITE);
  display.setCursor(6, 16);
  display.println("Zeen AI");
  display.setTextSize(1);
  display.setCursor(6, 42);
  display.println("Plug");
  display.display();
}

void showTextCentered(const char* line1, const char* line2=nullptr) {
  display.clearDisplay();
  display.setTextSize(1);
  display.setTextColor(SSD1306_WHITE);
  int16_t x1,y1;
  uint16_t w,h;
  display.getTextBounds(line1, 0, 0, &x1, &y1, &w, &h);
  display.setCursor((SCREEN_WIDTH - w)/2, 12);
  display.println(line1);
  if (line2) {
    display.getTextBounds(line2, 0, 0, &x1, &y1, &w, &h);
    display.setCursor((SCREEN_WIDTH - w)/2, 12 + 20);
    display.println(line2);
  }
  display.display();
}

void drawWiFiIcon(int x, int y) {
  // tiny WiFi icon (3 arcs)
  display.drawCircle(x,y-1,2,SSD1306_WHITE);
  display.drawCircle(x,y-1,4,SSD1306_WHITE);
  display.drawCircle(x,y-1,6,SSD1306_WHITE);
}

// ---------- Timer / countdown ----------
uint32_t remainingSeconds = 0;
unsigned long lastCountdownTick = 0;
bool countdownRunning = false;

void startCountdown(uint32_t seconds) {
  remainingSeconds = seconds;
  lastCountdownTick = millis();
  countdownRunning = true;
}

void stopCountdown() {
  countdownRunning = false;
}

void updateCountdown() {
  if (!countdownRunning) return;
  unsigned long now = millis();
  if (now - lastCountdownTick >= 1000) {
    unsigned long elapsed = (now - lastCountdownTick) / 1000;
    if (elapsed == 0) return;
    if (elapsed >= remainingSeconds) {
      remainingSeconds = 0;
      countdownRunning = false;
      // TODO: add end-of-countdown behavior (buzzer/relay) later
    } else {
      remainingSeconds -= elapsed;
      lastCountdownTick += elapsed * 1000;
    }
  }
}

String formatHMS(uint32_t sec) {
  uint32_t h = sec / 3600;
  uint32_t m = (sec % 3600) / 60;
  uint32_t s = sec % 60;
  char buf[16];
  sprintf(buf, "%02u:%02u:%02u", (unsigned)h, (unsigned)m, (unsigned)s);
  return String(buf);
}

// ---------- Mode selection UI ----------
int modeIndex = 0; // 0 = ONLINE, 1 = OFFLINE

void showModeSelect() {
  display.clearDisplay();
  display.setTextSize(1);
  display.setTextColor(SSD1306_WHITE);
  display.setCursor(6, 6);
  display.println("Select Mode");
  display.setTextSize(2);
  display.setCursor(12, 26);
  if (modeIndex == 0) display.print(">"); else display.print(" ");
  display.print("ONLINE");
  display.setCursor(12, 46);
  if (modeIndex == 1) display.print(">"); else display.print(" ");
  display.print("OFFLINE");
  display.display();
}

// ---------- Offline set-time UI ----------
int setCursor = 0; // 0=HH,1=MM,2=SS
uint32_t setHours = 0, setMinutes = 0, setSeconds = 0;
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
